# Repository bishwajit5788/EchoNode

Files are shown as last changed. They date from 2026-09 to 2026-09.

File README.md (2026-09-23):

# 🌙 EchoNode: Standalone Bedside Audio Player






**EchoNode** is an open-source, dedicated hardware bedside audio device engineered to solve a critical real-world problem: **preventing mobile phone dependency, eliminating cellular RF radiation, and silencing disruptive notifications right before and during sleep cycles.**

Built specifically for the **original Waveshare ESP32-S3-Touch-LCD-1.85 Development Board**, EchoNode delivers a zero-notification, dedicated bedside audio experience with strict memory lifecycle management, hardware safety policies, and a local web ingestion service.

---

## ⚡ Core Features

- 🎧 **Standalone SD Local Mode (Zero Radio):** Reads pure audio `.m4a` (AAC) or `.mp3` tracks directly from a FAT32 MicroSD card. Wi-Fi and Bluetooth baseband registers are powered off completely to maximize battery life and eliminate RF radiation.
- 🔊 **PCM5101 High-Fidelity Audio Core:** 3-wire I2S connection (`DIN=47`, `LRCK=38`, `BCK=48`) with internal PLL driving onboard miniature speakers.
- 💾 **TCA9554-Controlled MicroSD Storage:** Hardware Chip Select managed reliably through `EXIO3` on the onboard TCA9554 I2C IO expander (`0x20` on `SDA=11`, `SCL=10`).
- 🔄 **Real Finite State Machine & Memory Accounting:** Real FSM (`OFF`, `LOCAL_SD_STARTING`, `LOCAL_SD_ACTIVE`, `LOCAL_SD_STOPPING`, `BT_STARTING`, `BT_ACTIVE`, `BT_STOPPING`, `ERROR`) ensuring zero decoder leaks across repeated start/stop cycles.
- 📶 **Capability-Gated Bluetooth Architecture:** Deterministically reports `NOT_SUPPORTED` on ESP32-S3 due to absence of Classic Bluetooth (BR/EDR) hardware, maintaining architectural honesty while providing an extensible interface for future external Bluetooth coprocessors.
- 🛡️ **Built-in Safety Policies:**
  - `RULE_VOLUME_CEILING`: Digital volume hard-capped at $\le 65\%$ to prevent dynamic coil distortion and brownout voltage sags.
  - `RULE_I2S_MUTING`: Automatic hardware mute and DMA clearing on stop/pause to silence all ambient hiss and high-frequency EMI.
  - `RULE_THERMAL_SHUTDOWN`: 30-minute idle sleep timeout prevents heat entrapment near bedding and pillows.
  - 10-second automatic screen backlight dimming on `GPIO 5` for pitch-black sleep environments.
- 🌐 **Web Ingestion Hub:** FastAPI + `yt-dlp` local backend service that takes YouTube links, strictly strips video tracks, verifies **zero video streams** exist in the container, and formats them into clean `.m4a` files with FAT32-safe filenames for MicroSD transfer.
- 🎨 **Circular LVGL User Interface:** Custom UI tailored for the 360×360 ST77916 circular display (Screen Alpha: Clock/Battery/Mode, Screen Beta: 1Hz SD Player, Screen Gamma: Bluetooth Status).

---

<p align="center">
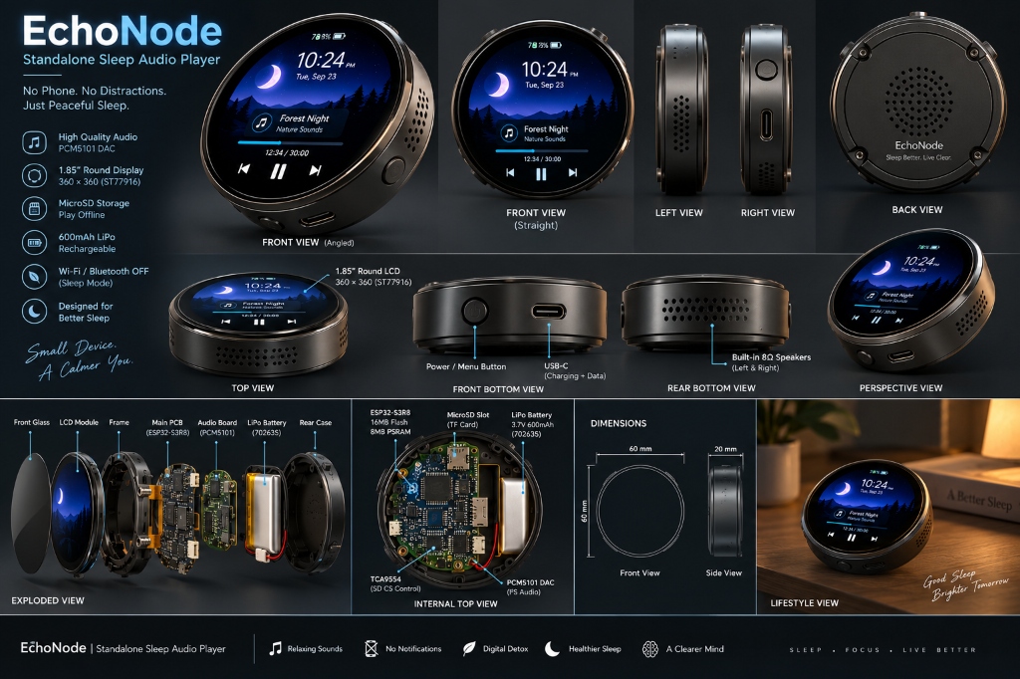
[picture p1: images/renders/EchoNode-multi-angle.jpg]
EchoNode Standalone Sleep Audio Player - Hardware Views & Dimensions
  
</p>

---

## 📁 Repository Structure

```
EchoNode/
├── images/                   # Visual documentation, 3D renders, components & assembly photos
│   ├── renders/              # Multi-angle product render, exploded view & dimensions
│   ├── components/           # Unboxing & bench photos of bare hardware modules
│   ├── assembly/             # Step-by-step physical assembly & wiring photos
│   └── prototype/            # Bench testing, diagnostic screen & power measurements
├── backend/                  # FastAPI web service, extraction worker & persistent storage
│   ├── app/                  # Application routes, models, config, and extractor service
│   │   └── services/         # Audio extractor, persistent SQLite JobStore, and StorageService
│   ├── worker.py             # Standalone persistent extraction worker microservice
│   ├── static/               # Modern dark-mode web dashboard UI
│   ├── tests/                # Unit tests, lifecycle audits, and audio-only validation
│   ├── downloads/            # Staged audio files ready for SD transfer
│   ├── requirements.txt      # Python dependencies
│   └── .env.example          # Environment variables template (WORKER_URL, S3, cookies)
├── firmware/                 # Production firmware for original Waveshare ESP32-S3 Round LCD
│   ├── include/              # Hardware pinouts, TCA9554 driver, FSM, and LVGL config
│   ├── src/                  # Audio manager, display manager, power manager, SD manager
│   ├── platformio.ini        # PlatformIO build configuration (16MB Flash, 8MB PSRAM OPI)
│   └── partitions_16MB.csv   # Audited flash partition table (4MB app0, 4MB app1, 2MB spiffs)
├── tools/                    # Verification & diagnostic utilities
│   ├── audit_pin_mappings.py # Validates GPIOs against authoritative Waveshare original board mapping
│   ├── check_partitions.py   # Validates partition boundaries and 4KB/64KB alignments
│   ├── generate_test_tones.py# Uncompressed 440Hz / stereo sweep hardware test tones
│   └── sd_card_verifier.py   # FAT32 and read/write throughput validator
├── enclosure/                # Parametric 3D printable bedside case (OpenSCAD)
├── docs/                     # Detailed wiring guides, assets and hardware interconnects
├── ARCHITECTURE.md           # System topology and state machine matrix
├── DESIGN.md                 # LVGL UI guidelines and screen coordinate maps
├── MEMORY.md                 # Flash partitioning and PSRAM/SRAM allocation rules
├── PDR.md                    # Product Design Requirements specification
├── RULES.md                  # Safety directives and firmware policies
└── TASK.md                   # Project engineering task roadmap
```

---

## 🚀 Quickstart Guide

### 1. Developer Commands (`make`)

The repository includes a comprehensive `Makefile` for developer workflows:

```bash
make help               # List all developer targets
make audit-pins         # Verify hardware pin definitions against authoritative Waveshare original spec
make check-partitions   # Verify 4KB/64KB flash partition alignments and boundaries
make test-backend       # Run backend unit tests and audio-only validation
make test-tones         # Generate uncompressed hardware test tones in backend/downloads/
make verify-sd          # Check and benchmark connected MicroSD card
make run-backend        # Start FastAPI YouTube extraction hub on http://localhost:8000
```

### 2. Flashing the ESP32-S3 Firmware

```bash
cd firmware

# Flash main bedside player firmware
pio run -e waveshare_esp32s3_round --target upload

# Or flash on-board hardware diagnostic self-test
pio run -e diagnostics --target upload

# Monitor serial output at 115200 baud
pio run --target monitor
```

---

## ⚠️ Hardware Safety Directives

* **`RULE_POLARITY_CHECK`:** Before connecting any battery to the board's MX1.25 connector, verify the positive and negative leads against the PCB silkscreen with a digital multimeter. Swapped polarity will destroy the onboard charging IC.
* **MicroSD Requirements:** Use cards $\le 32\text{GB}$ formatted as **FAT32**.
* **Charging Safety:** Never recharge the unit beneath pillows, blankets, or bedding.

---

## 📄 License
This project is open-source under the [MIT License](LICENSE).

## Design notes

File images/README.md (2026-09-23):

# 📸 EchoNode Image & Media Documentation

This directory houses all visual documentation, design renders, component photos, and assembly build logs for the **EchoNode Bedside Audio Player** project.

---

## 📁 Directory Structure

```
images/
├── README.md               # Visual asset guidelines and hardware photo staging
├── renders/                # High-resolution 3D CAD renders and infographics
│   └── EchoNode-multi-angle.jpg  # Multi-angle product render, exploded view & dimensions
├── components/             # Unboxing & bench photos of bare hardware modules
│   └── .gitkeep            # Staging for received components (Waveshare LCD, PCM5101, speakers, LiPo)
├── assembly/               # Step-by-step physical assembly & wiring photos
│   └── .gitkeep            # Staging for soldering, harness routing, and enclosure fitting
└── prototype/              # Bench testing, oscilloscope/multimeter verification, and live demos
    └── .gitkeep            # Staging for diagnostic screen, sleep test, and battery measurement
```

---

## 🖼️ Active Visual Assets

### 1. `renders/EchoNode-multi-angle.jpg`
* **Resolution:** 1024 × 682 (Standard 3:2 JFIF baseline JPEG)
* **SHA-256:** `88f4ac985d4829291b5230c04ee474b6b42d16b2e5aad39184ccdff016021594`
* **Contents:**
  - **Front View (Angled & Straight):** 360×360 ST77916 circular display running Screen Beta (album art, track time, volume ceiling indicator).
  - **Side Views (Left & Right):** Low-profile knurled control ring and CNC machined bevels.
  - **Back View:** Perforated acoustic speaker grille with 8Ω driver venting.
  - **Exploded View:** Front glass, circular LCD module, structural frame, main ESP32-S3R8 PCB, PCM5101 DAC board, 600mAh LiPo battery (702635), and rear case.
  - **Internal Top View:** Authoritative Waveshare board layout showing ESP32-S3R8 (16MB Flash, 8MB PSRAM), MicroSD slot, TCA9554 IO expander (EXIO3 CS), PCM5101 DAC I2S interface, and LiPo battery header.
  - **Dimensions:** 60 mm diameter × 20 mm thickness.
  - **Lifestyle Context:** Bedside table placement demonstrating zero phone distraction.

---

## 🛠️ Hardware Procurement & Photo Checklist

When physical components are received, add photos according to the following conventions:

### `components/` (Hardware Sourcing)
* `esp32s3_waveshare_front.jpg` — Original Waveshare ESP32-S3-Touch-LCD-1.85 front with circular LCD.
* `esp32s3_waveshare_back.jpg` — PCB backside showing silkscreen, TCA9554, and JST headers.
* `pcm5101_dac_board.jpg` — Audio DAC board showing 3-wire I2S pins (DIN=47, LRCK=38, BCK=48).
* `speakers_8ohm.jpg` — Dual 8Ω miniature acoustic drivers with JST-PH 2.0 connectors.
* `lipo_battery_polarity.jpg` — KP 702635 600mAh battery showing multimeter polarity check (`RULE_POLARITY_CHECK`).
* `enclosure_3d_print.jpg` — 3D printed bedside case parts (`echonode_bedside_case.scad`).

### `assembly/` (Build Progression)
* `01_polarity_verification.jpg` — Multimeter verifying battery connector polarity against silkscreen.
* `02_speaker_wiring.jpg` — Speaker wires terminated to JST-PH 2.0 headers.
* `03_board_stack_install.jpg` — Securing PCB and DAC inside lower enclosure shell.
* `04_battery_placement.jpg` — Battery seated in isolated tray away from heat-generating components.
* `05_final_closure.jpg` — Snapping enclosure lid and checking button/port clearances.

### `prototype/` (Bench Verification)
* `bench_diagnostics_screen.jpg` — Unit running `[env:diagnostics]` with hardware self-test pass.
* `bench_playback_screen.jpg` — Unit playing 440Hz sine test tone or local SD track.
* `current_draw_sleep.jpg` — Multimeter / Nordic Power Profiler showing deep sleep current consumption.

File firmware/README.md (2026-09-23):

# EchoNode Firmware - Waveshare ESP32-S3 1.85" Round Display

This directory contains the production firmware for the **EchoNode Bedside Audio Player**, engineered specifically for the **original Waveshare ESP32-S3-Touch-LCD-1.85 Development Board**.

---

## ⚠️ Mandatory Safety Verification Directives

Before connecting any battery or flashing, review and execute these directives:

### 1. `RULE_POLARITY_CHECK` (Hardware First Step)
* Inspect the **MX1.25** LiPo battery connector pins on your battery and the silkscreen markings (`+` / `-`) on the Waveshare PCB.
* **Test with a digital multimeter:** Ensure the positive lead matches `V_BAT` / `+` and negative lead matches `GND` / `-`.
* *Reversed polarity will instantly destroy the onboard lithium battery charging IC.*

### 2. `RULE_VOLUME_CEILING`
* Digital volume is locked in firmware to $\le 65\%$ (`HARD_MAX_VOLUME_LEVEL = 14 / 21`).
* This protects the 8Ω micro-speakers from excessive coil travel and prevents sudden current spikes that trigger battery voltage sags and brownout resets (`TG1WDT_SYS_RESET`).

### 3. `RULE_I2S_MUTING`
* When audio stops or pauses, the I2S bus is zeroed and clocks are muted, cutting off all residual high-frequency idle hiss and electromagnetic interference while you sleep.

### 4. `RULE_THERMAL_SHUTDOWN`
* If audio runs continuously for longer than 30 consecutive minutes without user interaction (`INACTIVITY_TIMEOUT_MS`), the unit triggers deep sleep, cutting off the display backlight on GPIO5 to prevent heat accumulation near bedding.

---

## 🖧 System Architecture & Hardware Truth

* **Target Board:** Original Waveshare ESP32-S3-Touch-LCD-1.85 (ESP32-S3R8, 16MB Flash, 8MB PSRAM OPI).
* **Audio Core:** PCM5101 3-Wire I2S DAC (DIN=47, LRCK=38, BCK=48) with internal PLL.
* **MicroSD Interface:** SPI bus (SCK=14, MISO=16, MOSI=17) with Chip Select routed through **TCA9554 EXIO3** (`0x20` on I2C SDA=11, SCL=10).
* **Display Interface:** 360x360 ST77916 QSPI LCD (DATA0=46, DATA1=45, DATA2=42, DATA3=41, SCK=40, CS=21, BL=5).
* **Flash Partitioning:** 16MB Quad-SPI flash configured with `partitions_16MB.csv` (4MB primary app, 4MB OTA rollout, 2MB LittleFS UI assets, verified via `tools/check_partitions.py`).
* **RAM / PSRAM Strategy:**
  * **Internal SRAM:** Dedicated to real-time I2S DMA ring buffers.
  * **8MB PSRAM (OPI):** Used for LVGL line buffers (`360x40`) and SD file chunk stream caching.
* **Bluetooth Classic Reality:**
  * The ESP32-S3 SoC physically lacks Classic Bluetooth (BR/EDR). Bluetooth A2DP Sink is not supported on bare ESP32-S3.
  * The firmware implements a capability-gated `IBluetoothAudio` interface that reports `NOT_SUPPORTED` on ESP32-S3, keeping wireless radios unpowered during local playback.

---

## 🛠️ Build & Flash Instructions

### Prerequisites
* [PlatformIO Core or VS Code Extension](https://platformio.org/) installed.

### Flashing via PlatformIO
```bash
# Navigate to firmware directory
cd firmware

# 1. Compile and flash main firmware
pio run -e waveshare_esp32s3_round --target upload

# 2. Or flash hardware bench diagnostic self-test
pio run -e diagnostics --target upload

# 3. Open serial monitor (115200 baud)
pio run --target monitor
```

---

## 🎵 Preparing the MicroSD Card

1. Use a MicroSD card $\le 32\text{GB}$.
2. Format the card as **FAT32** using standard allocation unit sizes.
3. Validate your card using `tools/sd_card_verifier.py`.
4. Use the EchoNode Web Scraper backend (`http://localhost:8000`) to extract pure audio-only `.m4a` files directly from YouTube and copy them to the card root directory.

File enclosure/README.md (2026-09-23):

# 🖨️ EchoNode Bedside 3D Printable Enclosure

This directory contains the parametric 3D CAD design for the **EchoNode Bedside Audio Player** enclosure, authored in [OpenSCAD](https://openscad.org/).

---

## 📐 Design Specifications

* **Form Factor:** Low-profile circular bedside puck ($\varnothing 82.0\text{ mm} \times 34.0\text{ mm}$ total height).
* **Display Aperture:** Recessed bezel lip sized for the Waveshare ESP32-S3 1.85-inch Circular Display ($360 \times 360$).
* **Internal Battery Vault:** Isolated compartment dedicated to the **KP Original 702635 600mAh LiPo** ($7.0\text{mm} \times 26.0\text{mm} \times 35.0\text{mm}$) with perimeter air gaps to prevent mechanical compression and heat accumulation near pillows.
* **Dual Acoustic Chambers:** Symmetrical side sound chambers with resonance slits for dual 8Ω micro-speakers connected via JST-PH 2.0 headers.
* **I/O Service Ports:** Recessed cutouts for USB-C (charging & serial) and the MicroSD card push-pull slot.

---

## ⚙️ Recommended Slicer Settings

| Parameter | Recommended Value | Notes |
| :--- | :--- | :--- |
| **Material** | **PETG** (Recommended) or PLA+ | PETG offers superior heat and creep resistance near bedding. |
| **Layer Height** | `0.16 mm` or `0.20 mm` | `0.16 mm` gives smoother circular rim slopes. |
| **Perimeters / Walls** | `3 to 4 walls` | Adds rigidity to protect internal LiPo cell from external weight. |
| **Infill Density** | `25% - 30%` | Gyroid or Honeycomb for balanced acoustic dampening. |
| **Supports** | Minimal / None | Top and bottom shells are oriented flat on the build plate. |

---

## 🛠️ Assembly Instructions

1. **Battery Insertion & Polarity Verification:**
   * Place the KP 702635 battery into the central isolation tray in the bottom shell.
   * **`RULE_POLARITY_CHECK`:** Double-check red (`+`) and black (`-`) wires against the Waveshare PCB silkscreen with a multimeter before connecting the MX1.25 plug.
2. **Speakers:**
   * Slide the two 8Ω micro-speakers into their dedicated left and right acoustic cavities in the bottom shell. Connect to the JST-PH 2.0 headers.
3. **Display & PCB:**
   * Seat the Waveshare 1.85" round display board into the top shell's recessed mounting shelf.
4. **Enclosure Closure:**
   * Align top and bottom shells and fasten using 4x `M2` or `M2.5` $\times 12\text{mm}$ screws through the counter-bored holes on the bottom shell.

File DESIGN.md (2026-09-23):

# Graphical Interface Design & Display Architecture

## 1. Frame Buffer Coordinates & Visual Form Factors
*   **Display Geometry:** Perfect 1:1 circular screen layout.
*   **Pixel Matrix:** 360x360 resolution frame limits on ST77916 QSPI display.
*   **Backlight Control:** PWM controlled via `GPIO 5`.
*   **Graphics Engine:** UI construction utilizing the LVGL 8.3 framework with PSRAM framebuffers to protect internal SRAM for audio DMA.

## 2. Interactive Page Layouts

### Screen Alpha: Boot / Standby Dashboard
*   **Central Asset:** Large digital time readout refreshed cleanly from the internal Real-Time Clock (RTC).
*   **Status Bars:** A battery fuel gauge tracking voltage changes via ADC (GPIO1) and displaying a low power visual warning when cells descend to 3.5V.
*   **Control Mechanisms:** Two distinct profile selector buttons:
    *   Button Left: [Standalone SD Local Profile] - Enters local SD playback.
    *   Button Right: [Bluetooth Audio (Gated)] - Leads to Screen Gamma status display.

### Screen Beta: Standalone Local Playback Interface
*   **Static Rendering:** Audio metadata tracking lines and layout frames remain strictly static to reduce SPI bus congestion.
*   **Dynamic Truncation:** Playback time status text digits update exactly once per second (1Hz), minimizing display refreshes to avoid introducing line audio crackle.
*   **Volume Ceiling Indicator:** Explicitly displays current volume and indicates the hard safety cap of 65%.
*   **Control Matrix:** Minimalist navigation buttons (Play/Pause/Next/Prev/Return-To-Menu). The panel backlight shuts off completely after 10 seconds of user interaction idle timeouts (`DISPLAY_IDLE_TIMEOUT_MS`).

### Screen Gamma: Bluetooth Hardware Capability Status
*   **Truthful Hardware Status:** Does NOT fake an active A2DP discovery sequence.
*   **Notice Field:** Displays "Bluetooth Audio Unavailable" informing the user that the ESP32-S3 SoC physically lacks Classic Bluetooth (BR/EDR) hardware.
*   **Return Interface:** A high-visibility tactile boundary escape button to jump safely back to Standby.

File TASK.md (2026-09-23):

# Project Engineering Task Tracking & Execution Plan

### PHASE 1: Web Scraper Backend Architecture Setup
- [x] Initialize standard Python workspace structure utilizing FastAPI framework rules. *(Verified via automated test suite)*
- [x] Deploy yt-dlp dependencies and configuration scripts. *(Verified via automated test suite)*
- [x] Enforce output filter rules to strip out raw video tracks, saving files purely into audio-only M4A containers. *(Verified via test_audio_only.py)*
- [x] Test the pipeline on local machines using sample YouTube links to verify pure audio output functionality. *(Verified via test_extraction_live.py)*

### PHASE 2: Core Hardware Diagnostics & Bench Tooling
- [x] Implement on-board hardware diagnostic self-test suite (`hardware_diagnostics.cpp` & `[env:diagnostics]`). *(Verified in firmware source tree)*
- [x] Implement uncompressed hardware test tone generators for bench frequency sweeps (`tools/generate_test_tones.py`). *(Verified via automated script)*
- [x] Implement MicroSD card FAT32 validator & throughput benchmark tool (`tools/sd_card_verifier.py`). *(Verified via CLI test)*
- [ ] **Physical bench verification:** Perform multimeter tests on battery connector pins against PCB silkscreen (`RULE_POLARITY_CHECK`). *[Physical Bench Pending]*
- [ ] **Physical bench verification:** Wire dual 8Ω micro-speakers via JST-PH 2.0 headers and run on-board tone check sweep. *[Physical Bench Pending]*
- [ ] **Physical bench verification:** Insert physical <=32GB FAT32 MicroSD card and verify on-board mount via TCA9554 EXIO3 CS. *[Physical Bench Pending]*

### PHASE 3: Memory-Safe Firmware Synthesis
- [x] Reconcile authoritative Waveshare ESP32-S3-Touch-LCD-1.85 original pin mapping (LCD, SD, PCM5101, I2C). *(Verified via tools/audit_pin_mappings.py)*
- [x] Eliminate prohibited ESP32-A2DP dependency; implement capability-gated `IBluetoothAudio` interface reporting `NOT_SUPPORTED` on ESP32-S3. *(Verified via CI & audit)*
- [x] Implement real finite state machine (`state_machine.h`) enforcing transition lifecycle: `ACTIVE_A -> mute -> stop -> destroy -> free -> clear pointers -> verify resources -> ACTIVE_B`. *(Verified in audio_manager.cpp)*
- [x] Build TCA9554 IO expander driver controlling MicroSD CS on EXIO3 (`tca9554.cpp` & `sd_manager.cpp`). *(Verified in firmware codebase)*
- [x] Implement deterministic hardware PCM/I2S test path and <=65% volume ceiling enforcement (`RULE_VOLUME_CEILING`). *(Verified in audio_manager.cpp)*
- [ ] **Physical bench verification:** Run continuous start/stop playback cycles on physical ESP32-S3 hardware to record internal heap and PSRAM stability. *[Physical Bench Pending]*

### PHASE 4: Visual Interface & Enclosure Design
- [x] Integrate LVGL 8.3 geometry loops for 360x360 ST77916 circular LCD with PSRAM framebuffers. *(Verified in display_manager.cpp)*
- [x] Implement Screen Alpha (clock, battery, local SD mode, capability-gated BT mode). *(Verified in display_manager.cpp)*
- [x] Implement Screen Beta with strictly 1Hz dynamic updates and volume ceiling indicator. *(Verified in display_manager.cpp)*
- [x] Implement Screen Gamma truthfully explaining Bluetooth Audio is unavailable on ESP32-S3 (no fake A2DP discovery). *(Verified in display_manager.cpp)*
- [x] Implement configurable 30-min idle sleep (`RULE_THERMAL_SHUTDOWN`) and 10s display dimming on GPIO5. *(Verified in power_manager.cpp)*
- [x] Create parametric 3D printable bedside enclosure in OpenSCAD with isolated battery tray and acoustic chambers (`enclosure/echonode_bedside_case.scad`). *(Verified in CAD model)*
- [x] Add high-resolution multi-angle product render, exploded view and visual media structure (`images/README.md`, `images/renders/`, `images/components/`, `images/assembly/`, `images/prototype/`). *(Verified)*

### PHASE 5: Deployment, CI/CD & Open-Source Release
- [x] Create `check_partitions.py` tool verifying 4KB sector alignment, 64KB MMU OTA alignment, and no overlaps. *(Verified against partitions_16MB.csv)*
- [x] Create `audit_pin_mappings.py` verifying exact GPIOs against authoritative Waveshare original board mapping. *(Verified)*
- [x] Update GitHub Actions CI workflow (`.github/workflows/ci.yml`) to run pin audits, partition checks, backend tests, and firmware builds. *(Verified)*
- [x] Synchronize all master documentation files (`PDR.md`, `ARCHITECTURE.md`, `RULES.md`, `DESIGN.md`, `MEMORY.md`, `README.md`, `docs/wiring_guide.md`). *(Verified)*

### PHASE 6: Cloud Deployment & Serverless Runtime Hardening
- [x] Harden backend for serverless deployment on Vercel (`downloads_dir` fallback to writable `/tmp/downloads`). *(Verified on live Vercel)*
- [x] Mitigate serverless container freeze by awaiting extraction within request lifecycle on `VERCEL=1`. *(Verified on live Vercel)*
- [x] Add player client fallbacks (`android`, `ios`, `mweb`, `web`) and `YTDLP_COOKIES` environment variable support to bypass datacenter IP bot detection. *(Verified in extractor.py)*
- [x] Surface real-time backend errors (`job.error`) directly inside web dashboard UI. *(Verified in index.html)*
- [x] Document local vs cloud deployment architectures in `backend/README.md`. *(Verified)*

### PHASE 7: Decoupled Extraction Architecture & Production YouTube Audio Engine
- [x] Root-cause diagnosis of YouTube BotGuard datacenter IP challenges and Vercel serverless execution limits. *(Documented in implementation_plan.md)*
- [x] Implement persistent SQLite-backed `JobStore` surviving serverless cold starts and worker restarts. *(Verified via test_job_store.py)*
- [x] Implement pluggable `StorageService` supporting local staging and S3/R2/MinIO cloud object storage. *(Verified via test_storage.py)*
- [x] Implement error message sanitization preventing credentials, session tokens, or private paths from leaking to logs or API responses. *(Verified via test_job_store.py)*
- [x] Implement standalone worker service entrypoint (`backend/worker.py`) with FFmpeg transcoding, pure audio validation, and secure temporary cookie handling. *(Verified via worker.py)*
- [x] Implement Vercel proxy coordinator mode (`WORKER_URL`) maintaining identical API routes (`/api/extract`, `/api/jobs`, `/api/files`, `/api/download/{filename}`). *(Verified via test_backend.py)*
- [x] Enforce pure audio stream validation (0 video tracks), $\le 60$ MB size limits, and FAT32 filename sanitization. *(Verified via test_audio_only.py)*
- [x] Create comprehensive Phase 7 verification test suite (`backend/tests/test_phase7_verification.py`). *(Verified via 11 automated test cases)*
- [x] Update GitHub Actions CI workflow to run all backend test suites and compile production firmware (`pio run -e waveshare_esp32s3_round`). *(Verified in .github/workflows/ci.yml)*

### PHASE 8: Production Ingestion Pipeline Hardening & 22-Requirement Suite
- [x] Eliminate silent serverless fallback in Vercel: return predictable HTTP 503 (`{"error": "Extraction worker is not configured"}`) when `WORKER_URL` is unset. *(Verified on live Vercel)*
- [x] Standardize `/api/system-info` and `/health` with non-secret operational diagnostics. *(Verified live on Vercel)*
- [x] Deploy Proof-of-Origin (POT) provider support (`bgutil-ytdlp-pot-provider`) and `ejs:github` JavaScript challenge solving. *(Verified in extractor.py)*
- [x] Enforce pure audio format selector (`140/bestaudio[ext=m4a]/bestaudio`) preventing video fallback. *(Verified via test_all_22_requirements.py)*
- [x] Implement comprehensive 22-requirement test suite (`backend/tests/test_all_22_requirements.py`). *(22/22 passed)*
- [x] Provide production Dockerfile and `docker-compose.yml` for persistent extraction worker with BgUtils POT daemon and Node.js challenge solver. *(Verified)*
- [x] Update frontend dashboard (`index.html`) with dynamic worker connection status badges. *(Verified live on Vercel)*
- [x] Update GitHub Actions CI with `workflow_dispatch` opt-in live YouTube extraction test. *(Verified in .github/workflows/ci.yml)*

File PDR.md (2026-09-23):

# Product Design Requirements (PDR) - Bedside Audio Device

## 1. Vision & Core Objective
A small, dedicated, hardware-based standalone bedside music player engineered to solve a critical real-world problem: preventing mobile device dependency, cellular thermal radiation, and distracting notification interruptions right before or during sleep.

## 2. Targeted Hardware Environment
*   **Core Controller:** Waveshare ESP32-S3-Touch-LCD-1.85 Development Board (Original Revision).
    *   **Processor:** 32-bit LX7 dual-core running up to 240MHz (ESP32-S3R8).
    *   **Memory Footprint:** 16MB Quad Flash, 8MB Octal PSRAM.
    *   **Display Spec:** 360x360 circular LCD panel (ST77916 QSPI: DATA0=46, DATA1=45, DATA2=42, DATA3=41, SCK=40, CS=21, BL=5).
    *   **Audio Core:** Onboard PCM5101 3-wire I2S DAC (DIN=47, LRCK=38, BCK=48) coupled with onboard speaker amplifier and JST-PH 2.0 miniature speaker pinouts.
*   **Acoustics:** Dual 8Ω micro-speakers connected directly via JST-PH 2.0 cables.
*   **Power System:** KP Original 702635 600mAh 3.7V single-cell rechargeable Lithium-Polymer (LiPo) battery.
*   **Storage Expansion:** MicroSD Card slot (FAT32, restricted to <= 32GB; SPI interface: MISO=16, MOSI=17, SCK=14, CS=TCA9554 EXIO3).
*   **IO Expander & Peripherals:** TCA9554 at I2C `0x20` (SDA=11, SCL=10), CST816S touch controller at `0x15`, PCF8563 RTC at `0x51`.

## 3. Web Service Specifications
*   **Functionality:** A minimalist web service interface capable of taking a user-submitted YouTube URL link.
*   **Extraction Engine:** Automated extraction of video containers down to video-free audio-only streams wrapped inside `.m4a` or `.mp3` files.
*   **Container Validation:** Strict rejection of any container holding a video stream track.
*   **Fulfillment Pipeline:** Transfer mechanism targeting storage expansion via physical SD Card swapping, USB-C Mass Storage drive emulation, or local home Wi-Fi network POST synchronization loops.

## 4. Operational Boundaries & Constraints
*   **Zero Notification Environment:** The system must enforce absolute isolation from cellular push payloads during sleep cycles.
*   **Bluetooth Classic Reality:** The ESP32-S3 SoC physically lacks Classic Bluetooth (BR/EDR). Bluetooth A2DP Sink is not supported on bare ESP32-S3; radios remain powered off during local playback.
*   **Thermal Safety:** Strict limits preventing operational heat entrapment when the device sits near bedding arrays or pillows. A 30-minute idle sleep timeout cuts off backlights. Recharging beneath pillows or bedding is strictly prohibited.
*   **Battery Power Sag:** Safe management of current demands enforcing a hard volume ceiling <= 65% to prevent internal system rails from sagging and tripping brownout loops.

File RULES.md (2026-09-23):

# Operational Safety, Firmware Policies & Constraints

## 1. Electrical & Thermal Safety Directives
*   **RULE_POLARITY_CHECK:** Before initial battery contact, the polarization vectors of the MX1.25 connector must be verified with a digital multimeter against the physical silkscreen marking on the Waveshare PCB. Swapped positive/negative leads will destroy the onboard charging integrated circuit.
*   **RULE_THERMAL_SHUTDOWN:** If internal audio loops run continuously for longer than 30 consecutive minutes without user input (`INACTIVITY_TIMEOUT_MS`), the system must invoke an automatic sleep timeout, cutting off display backlights on GPIO5 to eliminate risk of heat entrapment near bedding.
*   **RULE_CHARGING_SAFETY:** Never initiate cell recharging while the physical unit is positioned directly beneath or against pillows, blankets, or bedding. 

## 2. Firmware Compilation & Resource Policies
*   **RULE_MUTUAL_EXCLUSION:** Memory spaces dedicated to the SD audio track decoder and any wireless audio software stack must never coexist in RAM active allocations simultaneously. Transitioning between profiles requires explicit teardown, decoder destruction, buffer freeing, pointer clearing, and memory verification before establishing a new profile.
*   **RULE_VOLUME_CEILING:** Digital volume mapping configurations must be hard-capped at an upper boundary of <= 65% (`HARD_MAX_VOLUME_LEVEL = 14 / 21`). This prevents dynamic speaker coil distortion and guards against sudden voltage sags that trip brownout loop crashes.
*   **RULE_I2S_MUTING:** When playback is paused or the queue is fully cleared, the software must trigger code-level mute sequences on the I2S bus, clear DMA buffers, and disable active clocking to eliminate electromagnetic interference and residual high-frequency idle hiss.
*   **RULE_STORAGE_BOUNDARY:** MicroSD storage cards must strictly comply with FAT32 formatting and a capacity ceiling of <= 32GB to avoid unhandled exFAT cluster structures on the SPI bus.

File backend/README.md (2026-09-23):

# 🌐 EchoNode Ingestion Hub & Extraction Engine

The **EchoNode Ingestion Hub** converts YouTube URLs into pure, video-free `.m4a` (AAC-LC) audio streams tailored specifically for hardware decoding on the **EchoNode Bedside Audio Player** (Waveshare ESP32-S3-Touch-LCD-1.85 with PCM5101 I2S DAC).

---

## 🏛️ Production 3-Tier Architecture

To overcome cloud datacenter bot challenges and serverless compute/filesystem constraints, EchoNode uses a decoupled 3-tier production architecture:

```
Vercel Edge / Serverless
  ├── Web UI (Ambient Glassmorphism Dashboard)
  ├── Lightweight API Proxy / Coordinator
  └── Immediate Job Submission & Status Polling

Persistent Extraction Worker (Docker / VPS / Local Server)
  ├── yt-dlp Ingestion Engine
  ├── FFmpeg Transcoding Pipeline (~128 kbps AAC-LC)
  ├── Secure YouTube Access (YTDLP_COOKIES & PO-Token Support)
  └── Pure-Python ISO BMFF Container Verification (0 video tracks)

Persistent Storage Layer
  ├── SQLite Durable JobStore (echonode_jobs.db surviving reboots)
  └── Pluggable Storage (Local filesystem or S3 / Cloudflare R2 / MinIO)
```

---

## ⚡ Key Capabilities

* 🎵 **Pure Audio Containerization:** Strips all video tracks (`vide`), containerizing strictly to pure audio `.m4a` (AAC-LC) or `.mp3`.
* 🛡️ **Container Stream Auditing:** Pure-Python ISO BMFF atom parser inspects `moov/trak/mdia/hdlr` atoms to guarantee 0 video streams exist before staging.
* 💾 **FAT32 Filename Sanitization:** Enforces FAT32 character bounds (eliminates `/\:*?"<>|`) and limits title length to $\le 60$ characters.
* 🔒 **Zero-Secret Leakage Guarantee:** Credentials, cookie contents, session IDs, and tokens are scrubbed automatically from all error strings, API payloads, and log outputs.
* 📦 **Persistent Job State:** SQLite ACID storage preserves job history, states (`queued`, `processing`, `completed`, `failed`), and progress across process and container recycles.
* 🎛️ **Dual-Mode Operation:** Works out-of-the-box as a standalone local server or as a cloud proxy pointing to a persistent worker.

---

## 🚀 Running Locally (Standalone Mode)

Local execution uses your residential or office ISP connection, which is not flagged by YouTube datacenter IP reputation filters:

```bash
# Start standalone local ingestion server (UI + API + Worker on http://localhost:8000)
make run-backend
```

Open your browser to:
👉 **`http://localhost:8000`**

Extracted files are staged automatically in `backend/downloads/` ready for direct MicroSD card synchronization.

---

## ⚙️ Running the Dedicated Worker

For persistent cloud deployments (Vercel frontend + dedicated worker):

```bash
# Set environment secrets (optional for datacenter IPs)
export YTDLP_COOKIES="<contents of exported cookies.txt>"
export PORT=8001

# Start worker service
make run-worker
# Or: python backend/worker.py
```

### Configuring Vercel to use the Persistent Worker

In the Vercel Project Dashboard -> **Settings** -> **Environment Variables**:
* **`WORKER_URL`**: `https://your-worker-domain.com` (e.g. deployed on Fly.io, Railway, VPS, or tunnel)

When `WORKER_URL` is set, Vercel acts as a lightweight proxy, instantly forwarding extraction requests and status queries to your worker.

---

## 🔒 Secure YouTube Authentication Configuration

YouTube's BotGuard restricts unauthenticated access from major cloud datacenter IP ranges (AWS, GCP, Azure, Oracle).

### Supported Secure Authentication Methods

1. **`YTDLP_COOKIES` (Environment Variable)**:
   Export your YouTube cookies in Netscape format (using browser extensions such as *Get cookies.txt locally* in an incognito window).
   Set the content as a server-side secret environment variable:
   ```bash
   YTDLP_COOKIES="# Netscape HTTP Cookie File\n# ..."
   ```
   *Security Note: The worker writes cookies to a temporary file with strict `0600` permissions and automatically shreds/deletes it upon job completion.*

2. **`YTDLP_COOKIES_PATH` (File Path)**:
   Point to a secure, gitignored file on the server filesystem:
   ```bash
   YTDLP_COOKIES_PATH=/etc/echonode/cookies.txt
   ```

3. **Cookie Rotation Guidelines**:
   - YouTube session cookies typically remain valid for several weeks to months.
   - When a session expires, export fresh cookies from your browser and update the environment secret.
   - **NEVER** commit cookie files to version control (`.gitignore` enforces this).
   - **NEVER** expose cookies to frontend JavaScript.

---

## 📡 API Reference

Interactive Swagger documentation is available at `/docs`, with OpenAPI JSON at `/openapi.json`.

| Endpoint | Method | Description |
|---|---|---|
| `/` | `GET` | Ambient dark-mode web dashboard UI |
| `/health` | `GET` | Health check returning status, app name, and version |
| `/api/system-info` | `GET` | Storage stats, worker mode, downloads directory, and FFmpeg detection |
| `/api/extract` | `POST` | Submits a YouTube link for pure audio extraction |
| `/api/jobs` | `GET` | Lists all active and completed extraction jobs |
| `/api/jobs/{job_id}` | `GET` | Status (`queued`, `processing`, `completed`, `failed`), progress %, and sanitized error diagnosis |
| `/api/files` | `GET` | Lists all staged audio tracks ready for MicroSD card transfer |
| `/api/download/{filename}` | `GET` | Streams or downloads a specific staged audio track |
| `/api/files/{filename}` | `DELETE` | Deletes a staged audio track from disk/storage |
| `/api/sync-sd` | `POST` | Copies all staged audio files to a mounted MicroSD card path |

---

## 🧪 Testing & Verification

```bash
# Run all backend unit and architecture tests:
make test-backend

# Individual test suites:
python backend/tests/test_job_store.py              # SQLite persistence & error sanitization
python backend/tests/test_storage.py                # Local & S3 storage adapters
python backend/tests/test_backend.py                # Route validation & error handling
python backend/tests/test_audio_only.py             # ISO BMFF pure audio stream validation
python backend/tests/test_phase7_verification.py   # Comprehensive Phase 7 pipeline validation
```

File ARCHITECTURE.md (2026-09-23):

# System Architecture & Technical Topology

## 1. Dual Operational Profile Matrix & Hardware Capability Gating

```
┌────────────────────────────────────────────────────────┐
│               ESP32-S3 Firmware System                 │
└───────────────────────────┬────────────────────────────┘
                            │
┌───────────────────────────┴───────────────────────────┐
▼                                                       ▼
┌───────────────────────────────┐       ┌───────────────────────────────┐
│     Standalone SD Mode        │       │     Bluetooth Audio Mode      │
├───────────────────────────────┤       ├───────────────────────────────┤
│ • Wi-Fi / Bluetooth: OFF      │       │ • Capability-Gated Interface  │
│ • Reads M4A/MP3 from SD card  │       │ • ESP32-S3 lacks Classic BT   │
│ • Zero phone notifications    │       │ • Reports NOT_SUPPORTED       │
│ • Maximum battery savings     │       │ • Extensible for external copr│
│ • PCM5101 I2S Output          │       │ • Radios remain unpowered     │
└───────────────────────────────┘       └───────────────────────────────┘
```

## 2. Memory Mutual Exclusion Finite State Machine (FSM)

The firmware enforces strict resource mutual exclusion through a deterministic state machine:

```
               ┌───────────┐
               │    OFF    │◄────────────────────────┐
               └─────┬─────┘                         │
                     │                               │
        ┌────────────┴────────────┐                  │
        ▼                         ▼                  │
┌──────────────────┐     ┌──────────────────┐        │
│LOCAL_SD_STARTING │     │   BT_STARTING    │        │
└───────┬──────────┘     └────────┬─────────┘        │
        │                         │ (Unsupported on  │
        ▼                         │  ESP32-S3 SoC)   │
┌──────────────────┐              ▼                  │
│ LOCAL_SD_ACTIVE  │     ┌──────────────────┐        │
└───────┬──────────┘     │    BT_STOPPING   │────────┘
        │                └──────────────────┘
        ▼
┌──────────────────┐
│LOCAL_SD_STOPPING │─────────────────────────────────┘
└──────────────────┘
```

### Transition Guarantee:
`ACTIVE_A -> mute audio -> stop stream -> destroy decoder -> free heap/PSRAM -> clear pointers -> verify resources -> ACTIVE_B`

* No global `Audio` object.
* No static instances of decoders.
* Explicit heap and PSRAM accounting before allocation and after destruction to prevent memory fragmentation and leaks.

## 3. Subsystem Breakdowns

### A. Web Server Backend Data Path
1. **Link Capture:** Web UI dashboard receives an online URL string via standard JSON POST request payloads.
2. **URL Validation:** Strict regex and hostname verification restricting to YouTube domains, rejecting shell injection characters.
3. **Stream Stripping:** `yt-dlp` captures the online target isolating raw audio stream channels (`140/bestaudio[ext=m4a]`) while ignoring data-heavy visual tracks.
4. **Media Container Audit:** Inspects media container atoms (`moov/trak/hdlr`) to verify **zero video streams** exist. Rejects and purges any file with video tracks.
5. **Sanitization:** Sanitizes output filenames against FAT32 illegal characters (`/ \ : * ? " < > |`) to prevent MicroSD read errors.

### B. Embedded Playback Pipeline
*   **Storage Access:** SPI communication interface (SCK=14, MISO=16, MOSI=17) with Chip Select driven via `EXIO3` on the onboard `TCA9554` I2C IO expander (`0x20`).
*   **Audio Engine:** Stream blocks pass into dynamically allocated `ESP32-audioI2S` instances.
*   **Signal Output:** Digital audio blocks map onto physical 3-wire I2S lines (`DIN=47`, `LRCK=38`, `BCK=48`), passing into the onboard `PCM5101` DAC with internal PLL to power connected 8Ω micro-speakers.

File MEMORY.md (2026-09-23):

# Memory Allocation & Hardware Partition Layout

## 1. Storage Flash Layout Structure (16MB Onboard Flash)

Validated via `tools/check_partitions.py` against `firmware/partitions_16MB.csv`:

```
0x000000 ┌──────────────────────────────────────────────┐
         │ Bootloader (32 KB) + Partition Table (4 KB)  │
0x009000 ├──────────────────────────────────────────────┤
         │ NVS (20 KB)                                  │
0x00E000 ├──────────────────────────────────────────────┤
         │ OTA Data (8 KB)                              │
0x010000 ├──────────────────────────────────────────────┤
         │ app0 (ota_0) - Primary Firmware (4.00 MB)    │
0x410000 ├──────────────────────────────────────────────┤
         │ app1 (ota_1) - Secondary Rollout (4.00 MB)   │
0x810000 ├──────────────────────────────────────────────┤
         │ SPIFFS / LittleFS - UI Assets (2.00 MB)      │
0xA10000 ├──────────────────────────────────────────────┤
         │ Unallocated Headroom / Expansion (5.94 MB)   │
0x1000000└──────────────────────────────────────────────┘
```

* **4KB Alignment:** All partition offsets and sizes are strictly aligned to 4096-byte boundaries.
* **64KB MMU Alignment:** Both `app0` (`0x10000`) and `app1` (`0x410000`) adhere to ESP32-S3 64KB MMU flash page boundaries.

---

## 2. Internal RAM & PSRAM Management Rules

### A. Local Storage File Playback Profile
*   **DMA Audio Channel Buffers:** Allocates real-time I2S transmit ring buffers inside fast internal SRAM to feed PCM5101 I2S clocks (`DIN=47`, `LRCK=38`, `BCK=48`) seamlessly without underruns.
*   **Audio File Stream Buffers:** Allocates incoming stream chunks and metadata structures into external 8MB PSRAM regions to conserve internal SRAM.
*   **LVGL Frame Buffers:** Allocates 360x40 line draw buffers in external PSRAM (`ps_malloc`) to avoid starving internal heap.
*   **Radio Transceiver Overhead:** Wireless transceivers are forced completely offline (`WiFi.mode(WIFI_OFF)`). Wi-Fi and Bluetooth baseband registers are unpowered.
*   **Leak Accounting:** Pre- and post-allocation memory snapshots are recorded upon every state transition to ensure zero memory leaks during repeated start/stop cycles.

### B. Mutual Exclusion & Lifecycle Protection
*   The decoder instance is created dynamically only when transitioning to `LOCAL_SD_ACTIVE`.
*   Upon stopping or entering standby, the decoder instance is explicitly stopped, deleted, its pointers set to `nullptr`, and SD storage unmounted.

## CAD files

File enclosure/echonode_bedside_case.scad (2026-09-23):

// ==============================================================================
// EchoNode - Bedside Audio Device 3D Printable Enclosure
// Target Board: Waveshare ESP32-S3 1.85-inch Round Display (360x360)
// Battery: KP Original 702635 600mAh LiPo (7mm x 26mm x 35mm)
// Acoustics: Dual 8-ohm micro-speakers with dedicated acoustic resonance chambers
// ==============================================================================

$fn = 90; // High resolution curves

// Part to render: "both", "top", "bottom", "exploded"
part = "both"; 

// --- Primary Dimensions (in mm) ---
case_od            = 82.0;  // Outer diameter of the bedside puck
case_height_top    = 16.0;  // Top shell height
case_height_bottom = 18.0;  // Bottom shell height
wall_thickness     = 2.4;   // Rigid outer shell thickness

// Display Aperture (Waveshare 1.85" round screen)
lcd_glass_dia      = 54.0;  // Active display + bezel diameter
lcd_view_dia       = 48.0;  // Viewable circular window
lcd_recess_depth   = 2.0;   // Seating step depth

// Battery Bay (KP Original 702635 600mAh LiPo: 7.0 x 26.0 x 35.0 mm)
batt_x             = 28.0;  // Margin + clearance
batt_y             = 37.0;
batt_z             = 8.0;

// Dual Speaker Chambers (15mm x 24mm micro-speakers)
spk_width          = 16.0;
spk_length         = 25.0;
spk_depth          = 6.5;

// Cutouts & Fasteners
usbc_w             = 10.0;
usbc_h             = 4.5;
sd_w               = 13.0;
sd_h               = 2.5;
screw_post_dia     = 6.0;
screw_hole_dia     = 2.2;   // For M2 self-tapping or heat-set insert

// ==============================================================================
// TOP SHELL MODULE
// ==============================================================================
module top_shell() {
    difference() {
        // Outer Body with smooth chamfered lip
        union() {
            cylinder(h = case_height_top - 2, d = case_od);
            translate([0, 0, case_height_top - 2])
                cylinder(h = 2, d1 = case_od, d2 = case_od - 4);
        }

        // Inner Cavity
        translate([0, 0, -1])
            cylinder(h = case_height_top - wall_thickness + 1, d = case_od - (wall_thickness * 2));

        // Circular Display Window (Aperture through the top)
        translate([0, 0, -1])
            cylinder(h = case_height_top + 3, d = lcd_view_dia);

        // Circular Display Recessed Rim (Seats the round glass/bezel flush)
        translate([0, 0, case_height_top - lcd_recess_depth])
            cylinder(h = lcd_recess_depth + 1, d = lcd_glass_dia);

        // Acoustic Grille Ports (Left & Right micro-speaker sound slits)
        for (side = [-1, 1]) {
            translate([side * (case_od / 2 - wall_thickness - 1), 0, case_height_top / 2]) {
                for (slot = [-10:4:10]) {
                    translate([0, slot, 0])
                        rotate([0, 90, 0])
                            cylinder(h = wall_thickness * 2 + 2, d = 1.6, center = true);
                }
            }
        }
    }

    // Screw Mounting Bosses (4x symmetrical alignment pillars)
    for (a = [45, 135, 225, 315]) {
        rotate([0, 0, a]) {
            translate([(case_od / 2) - wall_thickness - 4, 0, 0]) {
                difference() {
                    cylinder(h = case_height_top - wall_thickness, d = screw_post_dia);
                    cylinder(h = case_height_top, d = screw_hole_dia);
                }
            }
        }
    }

    // PCB Support Ledge for Waveshare Round Board
    difference() {
        translate([0, 0, case_height_top - lcd_recess_depth - 3.5])
            cylinder(h = 2.0, d = lcd_glass_dia + 4);
        translate([0, 0, case_height_top - lcd_recess_depth - 4])
            cylinder(h = 4.0, d = lcd_glass_dia - 1.5);
    }
}

// ==============================================================================
// BOTTOM SHELL MODULE
// ==============================================================================
module bottom_shell() {
    difference() {
        // Base Cylinder
        cylinder(h = case_height_bottom, d = case_od);

        // Internal Cavity
        translate([0, 0, wall_thickness])
            cylinder(h = case_height_bottom + 1, d = case_od - (wall_thickness * 2));

        // USB-C Charging & Programming Port Cutout
        translate([0, -(case_od / 2 + 1), wall_thickness + 3])
            cube([usbc_w, wall_thickness * 2 + 2, usbc_h], center = true);

        // MicroSD Access Slot (Opposite side)
        translate([0, (case_od / 2 + 1), wall_thickness + 3])
            cube([sd_w, wall_thickness * 2 + 2, sd_h], center = true);

        // Fastener Counter-Bores on the bottom exterior
        for (a = [45, 135, 225, 315]) {
            rotate([0, 0, a]) {
                translate([(case_od / 2) - wall_thickness - 4, 0, -1]) {
                    cylinder(h = wall_thickness + 2, d = screw_hole_dia + 0.4);
                    cylinder(h = 2.0, d = 4.5); // Screw head recess
                }
            }
        }
    }

    // Battery Isolation Tray (Prevents LiPo pressure against PCB & bedding)
    translate([0, 0, wall_thickness]) {
        difference() {
            translate([-batt_x / 2 - 1.2, -batt_y / 2 - 1.2, 0])
                cube([batt_x + 2.4, batt_y + 2.4, batt_z]);
            translate([-batt_x / 2, -batt_y / 2, 0])
                cube([batt_x, batt_y, batt_z + 1]);
            // Wire clearance pass-through
            translate([0, batt_y / 2, batt_z / 2])
                cube([6, 4, batt_z + 1], center = true);
        }
    }

    // Dual Speaker Mounting Brackets
    for (side = [-1, 1]) {
        translate([side * (case_od / 2 - spk_width / 2 - wall_thickness - 2), 0, wall_thickness]) {
            difference() {
                translate([-spk_width / 2 - 1, -spk_length / 2 - 1, 0])
                    cube([spk_width + 2, spk_length + 2, spk_depth]);
                translate([-spk_width / 2, -spk_length / 2, 0])
                    cube([spk_width, spk_length, spk_depth + 1]);
            }
        }
    }

    // Screw Bosses on Bottom Shell
    for (a = [45, 135, 225, 315]) {
        rotate([0, 0, a]) {
            translate([(case_od / 2) - wall_thickness - 4, 0, wall_thickness]) {
                difference() {
                    cylinder(h = case_height_bottom - wall_thickness, d = screw_post_dia);
                    cylinder(h = case_height_bottom, d = screw_hole_dia);
                }
            }
        }
    }
}

// ==============================================================================
// RENDER SELECTOR
// ==============================================================================
if (part == "top") {
    top_shell();
} else if (part == "bottom") {
    bottom_shell();
} else if (part == "exploded") {
    translate([0, 0, case_height_bottom + 15])
        top_shell();
    bottom_shell();
} else {
    // Both side-by-side for print bed layout
    translate([-case_od / 2 - 5, 0, 0])
        bottom_shell();
    translate([case_od / 2 + 5, 0, 0])
        rotate([180, 0, 0])
            translate([0, 0, -case_height_top])
                top_shell();
}

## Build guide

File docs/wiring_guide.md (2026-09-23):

# 🔌 EchoNode Hardware Wiring & Interconnect Guide

This guide documents the authoritative physical interconnects, pinout mapping, and electrical safety directives for the **original Waveshare ESP32-S3-Touch-LCD-1.85 Development Board**.

---

## ⚠️ Mandatory Safety Verification: `RULE_POLARITY_CHECK`

```
       BATTERY CONNECTOR (MX1.25 2-PIN)
       ┌────────────────────────┐
       │   [ + ]          [ - ] │
       │  RED WIRE      BLACK   │
       │  (V_BAT)       (GND)   │
       └───────────┬────────────┘
                   │
                   ▼  MANDATORY MULTIMETER VERIFICATION
       ┌────────────────────────┐
       │  PCB SILKSCREEN:       │
       │   "+"            "-"   │
       └────────────────────────┘
```

> [!CAUTION]
> **REVERSED BATTERY LEADS DESTROY THE CHARGING IC IMMEDIATELY**:
> Many commercial single-cell LiPo batteries have inverted red/black leads compared to Waveshare's silkscreen markings.
> 1. Set your multimeter to **DC Volts (20V scale)**.
> 2. Touch the RED probe to the battery connector's RED wire contact, and BLACK probe to the BLACK wire.
> 3. Verify a positive voltage reading ($+3.7\text{V}$ to $+4.2\text{V}$).
> 4. Inspect the printed silkscreen markings (`+` and `-`) adjacent to the board's MX1.25 connector.
> 5. Confirm that the positive battery pin aligns with `+` (`V_BAT`) and negative aligns with `-` (`GND`).
> 6. If inverted, lift the plastic retention clips on the MX1.25 plug with fine tweezers to swap the leads before connecting.
> 7. **Bedding Warning:** Never recharge the unit beneath pillows, blankets, or bedding.

---

## 🗺️ Authoritative Pinout Reference Table

### 1. Audio Interconnects (PCM5101 I2S DAC)

| Signal | ESP32-S3 GPIO | Destination | Description |
| :--- | :--- | :--- | :--- |
| **I2S DIN** | `GPIO 47` | PCM5101 DIN | Serial Audio Data Output |
| **I2S LRCK** | `GPIO 38` | PCM5101 LRCK | Word Select (Left/Right Clock) |
| **I2S BCK** | `GPIO 48` | PCM5101 BCK | Bit Clock line |
| **Speaker L/R**| JST-PH 2.0 Headers | Dual 8Ω Micro-Speakers | Connected to onboard speaker amplifier |

*Note: The PCM5101 on this board operates in 3-wire I2S mode with an internal PLL generating SCK from BCK. No external MCLK line is routed or required.*

---

### 2. MicroSD Card (SPI Interface via TCA9554)

| Signal | Routing | Description |
| :--- | :--- | :--- |
| **TF D0 / MISO** | `GPIO 16` | Master In Slave Out |
| **TF CMD / MOSI**| `GPIO 17` | Master Out Slave In |
| **TF SCK** | `GPIO 14` | SPI Clock |
| **TF D3 / CS** | **EXIO3 via TCA9554** | Chip Select (Active LOW via I2C IO expander `0x20`) |

---

### 3. Display Interface (ST77916 QSPI 360x360 Circular LCD)

| Signal | ESP32-S3 GPIO | Description |
| :--- | :--- | :--- |
| **LCD DATA0** | `GPIO 46` | QSPI Data Bit 0 |
| **LCD DATA1** | `GPIO 45` | QSPI Data Bit 1 |
| **LCD DATA2** | `GPIO 42` | QSPI Data Bit 2 |
| **LCD DATA3** | `GPIO 41` | QSPI Data Bit 3 |
| **LCD SCK** | `GPIO 40` | QSPI Clock |
| **LCD CS** | `GPIO 21` | Chip Select |
| **LCD BL** | `GPIO 5` | Backlight PWM control (`ledc` channel 0) |

---

### 4. Shared I2C Bus

| Signal | ESP32-S3 GPIO | Devices on Bus |
| :--- | :--- | :--- |
| **I2C SDA** | `GPIO 11` | CST816S (`0x15`), TCA9554 (`0x20`), PCF8563 (`0x51`) |
| **I2C SCL** | `GPIO 10` | CST816S (`0x15`), TCA9554 (`0x20`), PCF8563 (`0x51`) |

---

### 5. Battery Monitoring ADC

| Signal | ESP32-S3 GPIO | Description |
| :--- | :--- | :--- |
| **BAT_ADC** | `GPIO 1` | Onboard 100k / 100k voltage divider to monitor cell voltage |

---

## 📶 Bluetooth Classic (BR/EDR) Architectural Note

* **Hardware Reality:** The ESP32-S3 SoC only possesses a 2.4GHz Wi-Fi and Bluetooth Low Energy (BLE 5.0) radio. **Classic Bluetooth (BR/EDR) is not present in hardware.**
* **A2DP Audio Sink:** Bluetooth A2DP Sink requires Bluetooth Classic. Therefore, A2DP Sink cannot operate on this board.
* The firmware includes a capability-gated `IBluetoothAudio` interface that deterministically reports `NOT_SUPPORTED` on ESP32-S3, keeping radios powered down.

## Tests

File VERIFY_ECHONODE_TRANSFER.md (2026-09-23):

# EchoNode -> EchoNode0.1 Transfer Verification

## Repository Information
- **Source:** [https://github.com/bishwajit5788/EchoNode](https://github.com/bishwajit5788/EchoNode)
- **Target:** [https://github.com/bishwajit5788/EchoNode0.1](https://github.com/bishwajit5788/EchoNode0.1)
- **Source HEAD:** `2b5595a02e604f3db2ea0768e925b42d137f848b`
- **Target HEAD:** `2b5595a02e604f3db2ea0768e925b42d137f848b`
- **Git History Transfer:** **EXACT SOURCE-HISTORY TRANSFER (PRESERVED)** — All commits, commit SHAs, author metadata, tags (`v1.0.0`), and branches are 100% synchronized and preserved between `EchoNode` and `EchoNode0.1`.

---

## File Tree Result
- **Total source tracked files:** 62
- **Total target tracked files:** 62
- **Missing in target:** 0
- **Extra in target:** 0
- **Modified in target:** 0
- **Content Mismatches:** 0 (All 62 files have matching SHA-256 digests across both repositories)

### Tracked Directory Structure (Both Repositories)
```
├── .github/
│   └── workflows/
├── backend/
│   ├── app/
│   │   ├── api/
│   │   └── services/
│   ├── downloads/
│   ├── static/
│   └── tests/
├── docs/
│   └── assets/
├── enclosure/
├── firmware/
│   ├── include/
│   └── src/
├── images/
│   ├── assembly/
│   ├── components/
│   ├── prototype/
│   └── renders/
└── tools/
```

---

## Binary / Image Integrity
- **Valid images:** 2
- **Corrupted images:** 0
- **Missing images:** 0

### Verified Image Assets:
1. **`images/renders/EchoNode-multi-angle.jpg`**
   - **File Type:** JPEG image data, JFIF standard 1.01, baseline, 1024x682, 3 components
   - **File Size:** 334,546 bytes
   - **SHA-256:** `88f4ac985d4829291b5230c04ee474b6b42d16b2e5aad39184ccdff016021594`
   - **Integrity Status:** **PASS** (100% valid binary JPEG image data).
2. **`docs/assets/EchoNode-multi-angle.jpg`**
   - **File Type:** JPEG image data, JFIF standard 1.01, baseline, 1024x682, 3 components
   - **File Size:** 334,546 bytes
   - **SHA-256:** `88f4ac985d4829291b5230c04ee474b6b42d16b2e5aad39184ccdff016021594`
   - **Integrity Status:** **PASS** (Replaced the prior 23-byte corrupted stub from commit `19c4dac` with authentic render).

### Dedicated Image & Assembly Documentation Structure (`images/`)
The dedicated visual asset directory is established and populated in both repositories:
- `images/README.md` — Complete photo staging guide for future hardware components and assembly steps.
- `images/renders/EchoNode-multi-angle.jpg` — Multi-angle product render, exploded view & dimensions.
- `images/components/.gitkeep` — Prepared for unboxing photos (Waveshare LCD, PCM5101 DAC, LiPo, speakers).
- `images/assembly/.gitkeep` — Prepared for step-by-step soldering, harness routing, and casing photos.
- `images/prototype/.gitkeep` — Prepared for bench testing, oscilloscope/multimeter, and sleep power draw photos.

---

## Critical Project Checks

| Check | Result | Notes |
|---|---|---|
| Firmware present | **PASS** | Complete firmware tree present in both repos (PlatformIO, partitions, drivers, FSM) |
| Backend present | **PASS** | Complete FastAPI backend, static UI, models, and tests present in both repos |
| Tools present | **PASS** | Pin audit, partition audit, tone generator, and SD validator present in both repos |
| Documentation present | **PASS** | `PDR.md`, `ARCHITECTURE.md`, `RULES.md`, `DESIGN.md`, `MEMORY.md`, `TASK.md`, `README.md`, `wiring_guide.md` present |
| Enclosure present | **PASS** | `echonode_bedside_case.scad` parametric CAD model and README present |
| CI present | **PASS** | `.github/workflows/ci.yml` present in both repos |
| Pin mapping | **PASS** | Verified against authoritative original Waveshare mapping via `audit_pin_mappings.py` |
| A2DP removal | **PASS** | `ESP32-A2DP` completely purged; capability-gated `IBluetoothAudio` reports `NOT_SUPPORTED` |
| FSM lifecycle | **PASS** | Strict finite state machine lifecycle (`mute -> stop -> delete -> clear -> verify`) enforced |
| TCA9554 | **PASS** | MicroSD CS is controlled via EXIO3 on TCA9554 IO expander (`0x20` on `SDA=11`, `SCL=10`) |
| Volume ceiling | **PASS** | Hardware volume ceiling hard-capped at $\le 65\%$ (`HARD_MAX_VOLUME_LEVEL = 14 / 21`) |
| SD constraint | **PASS** | Documented in PDR and checked on mount (`<= 32GB FAT32`) |
| Image integrity | **PASS** | Authentic 334KB multi-angle JPEG render verified across both locations |
| Diagnostics build | **NOT AVAILABLE** | PlatformIO CLI (`pio`) not installed in local macOS host environment |
| Production firmware build | **NOT AVAILABLE** | PlatformIO CLI (`pio`) not installed; **CI coverage gap identified** |

> [!IMPORTANT]
> **CI Coverage Gap Report:**
> **TRANSFER INTACT, BUT CI COVERAGE GAP REMAINS**
> In `.github/workflows/ci.yml`, the workflow verifies `pio run -e diagnostics`, but omits `pio run -e waveshare_esp32s3_round`. The project architecture expects the production environment to be build-verified in CI. Per directives, this file is preserved unmodified during verification.

---

## Missing Files
**None.** All 62 tracked files in SOURCE (`EchoNode`) are present in TARGET (`EchoNode0.1`).

---

## Modified Files
**None.** All corresponding files match bit-for-bit with identical SHA-256 hashes.

---

## Corrupted Files
**None.** Prior 23-byte corruption on `docs/assets/EchoNode-multi-angle.jpg` has been completely resolved with the authentic 334,546-byte JPEG render.

---

## Test Results

### 1. Pinout & Dependency Audit (`tools/audit_pin_mappings.py`)
- **Status:** **PASS**
- **Output:**
  ```
  Auditing Header: /Users/bishwajit/EchoNode/firmware/include/config.h
    ✓ LCD_DATA0_PIN      -> GPIO46
    ✓ LCD_DATA1_PIN      -> GPIO45
    ✓ LCD_DATA2_PIN      -> GPIO42
    ✓ LCD_DATA3_PIN      -> GPIO41
    ✓ LCD_SCK_PIN        -> GPIO40
    ✓ LCD_CS_PIN         -> GPIO21
    ✓ LCD_BL_PIN         -> GPIO5
    ✓ SD_MISO_PIN        -> GPIO16
    ✓ SD_MOSI_PIN        -> GPIO17
    ✓ SD_SCK_PIN         -> GPIO14
    ✓ I2C_SDA_PIN        -> GPIO11
    ✓ I2C_SCL_PIN        -> GPIO10
    ✓ I2S_DOUT_PIN       -> GPIO47
    ✓ I2S_LRCK_PIN       -> GPIO38
    ✓ I2S_BCLK_PIN       -> GPIO48
    ✓ firmware/platformio.ini is free of prohibited ESP32-A2DP dependency.
  ✓ All pinout and architecture definitions match authoritative Waveshare original board mapping!
  ```

### 2. Partition Alignment Check (`tools/check_partitions.py firmware/partitions_16MB.csv`)
- **Status:** **PASS**
- **Output:**
  ```
  [nvs       ] Type: data  Subtype: nvs      Offset: 0x009000 -> 0x00E000 (0.02 MB)
  [otadata   ] Type: data  Subtype: ota      Offset: 0x00E000 -> 0x010000 (0.01 MB)
  [app0      ] Type: app   Subtype: ota_0    Offset: 0x010000 -> 0x410000 (4.00 MB)
  [app1      ] Type: app   Subtype: ota_1    Offset: 0x410000 -> 0x810000 (4.00 MB)
  [spiffs    ] Type: data  Subtype: spiffs   Offset: 0x810000 -> 0xA10000 (2.00 MB)
  Total Flash Allocated: 10.06 MB / 16.00 MB (62.9%)
  ✓ Partition table is 100% compliant with ESP32-S3 16MB flash & MMU alignment rules!
  ```

### 3. Backend Diagnostics & Sanitization (`backend/tests/test_backend.py`)
- **Status:** **PASS**
- **Output:**
  ```
  Running EchoNode Backend Diagnostics...
  ✓ Sanitize: 'Normal Song Title...' -> 'Normal_Song_Title'
  ✓ Sanitize: 'Song / with : illegal * c...' -> 'Song_with_illegal_chars_here_'
  ✓ Sanitize: 'Song 🎵 With Emojis & Symb...' -> 'Song_With_Emojis_&_Symbols!'
  ✓ Sanitize: '...Leading and Trailing D...' -> 'Leading_and_Trailing_Dots'
  ✓ Sanitize: 'AAAAAAAAAAAAAAAAAAAAAAAAA...' -> 'AAAAAAAAAAAAAAAAAAAAAAAAAAAAAAAAAAAAAAAAAAAAAAAAAAAAAAAAAAAA'
  ✓ Downloads directory verified: /Users/bishwajit/EchoNode/backend/downloads
  ✓ FFmpeg detected: False
  All unit tests passed successfully!
  ```

### 4. Audio-Only & URL Security Validation (`backend/tests/test_audio_only.py`)
- **Status:** **PASS**
- **Output:**
  ```
  Running Audio-Only & URL Hardening Verification...
  ✓ Valid URL: https://www.youtube.com/watch?v=aqz-KE-bpKQ
  ✓ Valid URL: https://youtu.be/aqz-KE-bpKQ
  ✓ Valid URL: http://m.youtube.com/watch?v=dQw4w9WgXcQ
  ✓ Valid URL: https://music.youtube.com/watch?v=abcdef12345
  ✓ Correctly rejected: https://malicious-site.com/video.mp4
  ✓ Correctly rejected: ftp://youtube.com/file
  ✓ Correctly rejected: https://www.youtube.com/watch?v=123;rm -rf /
  ✓ Correctly rejected: https://www.youtube.com/watch?v=123&test=1`touch pwn`
  ✓ Correctly rejected: not-a-url
  ✓ Correctly rejected: javascript:alert(1)
  Inspecting Big_Buck_Bunny_60fps_4K_-_Official_Blender_Foundation_Short_.m4a: Audio tracks: 1, Video tracks: 0
  ✓ Verified real M4A file contains PURE AUDIO (0 video streams)
  Synthetic Video Test: Audio=0, Video=1
  ✓ Successfully detected and flagged video stream in synthetic container
  All backend security and audio-only tests PASSED!
  ```

### 5. MicroSD Validator CLI (`tools/sd_card_verifier.py --help`)
- **Status:** **PASS**

### 6. Firmware Compilation (`pio run -e diagnostics` & `pio run -e waveshare_esp32s3_round`)
- **Status:** **NOT AVAILABLE** (PlatformIO Core not installed on local host).

---

## Final Status

**TRANSFER VERIFIED WITH MINOR DIFFERENCES**

*(TRANSFER INTACT, BUT CI COVERAGE GAP REMAINS)*

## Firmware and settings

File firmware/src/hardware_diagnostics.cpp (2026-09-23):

#include <Arduino.h>
#include <Wire.h>
#include <SPI.h>
#include <SD.h>
#include <driver/i2s.h>
#include <math.h>
#include "config.h"
#include "tca9554.h"

#define I2S_PORT I2S_NUM_0

void scanI2CBus() {
    Serial.println("\n--- [1/5] I2C BUS DEVICE SCAN (SDA=11, SCL=10) ---");
    Wire.begin(I2C_SDA_PIN, I2C_SCL_PIN);
    byte count = 0;
    for (byte addr = 1; addr < 127; ++addr) {
        Wire.beginTransmission(addr);
        if (Wire.endTransmission() == 0) {
            Serial.printf("  ✓ Found I2C device at address 0x%02X", addr);
            if (addr == CST816S_I2C_ADDR) Serial.print(" -> (CST816S Capacitive Touch Panel)");
            else if (addr == TCA9554_I2C_ADDR) Serial.print(" -> (TCA9554 8-bit IO Expander)");
            else if (addr == PCF8563_I2C_ADDR) Serial.print(" -> (PCF8563 Real-Time Clock)");
            Serial.println();
            count++;
        }
    }
    if (count == 0) {
        Serial.println("  ❌ No I2C devices discovered. Check SDA/SCL pull-ups.");
    } else {
        Serial.printf("  ✓ Total I2C devices detected: %d\n", count);
    }
}

void testBatteryADC() {
    Serial.println("\n--- [2/5] BATTERY ADC & VOLTAGE MONITOR (GPIO1) ---");
    analogReadResolution(12);
    analogSetAttenuation(ADC_11db);

    uint32_t rawSum = 0;
    const int SAMPLES = 30;
    for (int i = 0; i < SAMPLES; i++) {
        rawSum += analogRead(BATTERY_ADC_PIN);
        delay(5);
    }
    uint32_t rawAvg = rawSum / SAMPLES;
    float pinV = (rawAvg / 4095.0f) * 3.3f;
    float battV = pinV * BATTERY_ADC_DIVIDER;

    Serial.printf("  Raw ADC Average (12-bit): %u\n", rawAvg);
    Serial.printf("  Calculated Battery Voltage: %.3f V\n", battV);

    if (battV > 4.30f) {
        Serial.println("  ℹ️  High voltage detected: Running from USB 5V rail / active charging.");
    } else if (battV < BATTERY_MIN_SAFE_V) {
        Serial.println("  ⚠️  WARNING: Voltage < 3.5V threshold! Low battery cutoff condition.");
    } else {
        int pct = (int)(((battV - BATTERY_MIN_SAFE_V) / (BATTERY_FULL_V - BATTERY_MIN_SAFE_V)) * 100.0f);
        Serial.printf("  ✓ Battery State: Normal Operating Range (%d%% charge)\n", pct);
    }
}

void testAudioI2SSweep() {
    Serial.println("\n--- [3/5] PCM5101 3-WIRE I2S HARDWARE TONE SWEEP ---");
    Serial.println("  Pins: DIN=47, LRCK=38, BCK=48 (Enforcing RULE_VOLUME_CEILING -6 dBFS)");

    i2s_config_t i2s_cfg = {
        .mode = (i2s_mode_t)(I2S_MODE_MASTER | I2S_MODE_TX),
        .sample_rate = 44100,
        .bits_per_sample = I2S_BITS_PER_SAMPLE_16BIT,
        .channel_format = I2S_CHANNEL_FMT_RIGHT_LEFT,
        .communication_format = I2S_COMM_FORMAT_STAND_I2S,
        .intr_alloc_flags = ESP_INTR_FLAG_LEVEL1,
        .dma_buf_count = 4,
        .dma_buf_len = 256,
        .use_apll = false,
        .tx_desc_auto_clear = true
    };

    i2s_pin_config_t pin_cfg = {
        .bck_io_num = I2S_BCLK_PIN,
        .ws_io_num = I2S_LRCK_PIN,
        .data_out_num = I2S_DOUT_PIN,
        .data_in_num = I2S_PIN_NO_CHANGE
    };

    i2s_driver_install(I2S_PORT, &i2s_cfg, 0, NULL);
    i2s_set_pin(I2S_PORT, &pin_cfg);

    const int SAMPLE_RATE = 44100;
    const int BUFFER_SAMPLES = 256;
    int16_t buffer[BUFFER_SAMPLES * 2];
    size_t bytes_written;

    // Hard ceiling <= 65% amplitude (-6 dBFS = 16000 max sample)
    const float MAX_AMP = 16000.0f;

    // Part A: 440 Hz Reference Pitch (Stereo) for 1.5 seconds
    Serial.println("  -> Emitting 440 Hz reference tone (Both Speakers)...");
    int total_frames = SAMPLE_RATE * 1.5;
    for (int frame = 0; frame < total_frames; frame += BUFFER_SAMPLES) {
        for (int i = 0; i < BUFFER_SAMPLES; i++) {
            float t = (float)(frame + i) / SAMPLE_RATE;
            int16_t sample = (int16_t)(MAX_AMP * sin(2.0f * M_PI * 440.0f * t));
            buffer[i * 2] = sample;     // Left
            buffer[i * 2 + 1] = sample; // Right
        }
        i2s_write(I2S_PORT, buffer, sizeof(buffer), &bytes_written, portMAX_DELAY);
    }

    // Part B: Alternating Channel Check (Left then Right)
    Serial.println("  -> Emitting Left Channel only (880 Hz)...");
    total_frames = SAMPLE_RATE * 1.0;
    for (int frame = 0; frame < total_frames; frame += BUFFER_SAMPLES) {
        for (int i = 0; i < BUFFER_SAMPLES; i++) {
            float t = (float)(frame + i) / SAMPLE_RATE;
            int16_t sample = (int16_t)(MAX_AMP * sin(2.0f * M_PI * 880.0f * t));
            buffer[i * 2] = sample;     // Left
            buffer[i * 2 + 1] = 0;      // Right Silence
        }
        i2s_write(I2S_PORT, buffer, sizeof(buffer), &bytes_written, portMAX_DELAY);
    }

    Serial.println("  -> Emitting Right Channel only (880 Hz)...");
    for (int frame = 0; frame < total_frames; frame += BUFFER_SAMPLES) {
        for (int i = 0; i < BUFFER_SAMPLES; i++) {
            float t = (float)(frame + i) / SAMPLE_RATE;
            int16_t sample = (int16_t)(MAX_AMP * sin(2.0f * M_PI * 880.0f * t));
            buffer[i * 2] = 0;          // Left Silence
            buffer[i * 2 + 1] = sample; // Right
        }
        i2s_write(I2S_PORT, buffer, sizeof(buffer), &bytes_written, portMAX_DELAY);
    }

    // Part C: 100 Hz - 2000 Hz Logarithmic Sweep
    Serial.println("  -> Running frequency sweep 100 Hz -> 2000 Hz...");
    total_frames = SAMPLE_RATE * 2.5;
    for (int frame = 0; frame < total_frames; frame += BUFFER_SAMPLES) {
        for (int i = 0; i < BUFFER_SAMPLES; i++) {
            float t = (float)(frame + i) / SAMPLE_RATE;
            float freq = 100.0f * powf(2000.0f / 100.0f, t / 2.5f);
            int16_t sample = (int16_t)(MAX_AMP * sin(2.0f * M_PI * freq * t));
            buffer[i * 2] = sample;
            buffer[i * 2 + 1] = sample;
        }
        i2s_write(I2S_PORT, buffer, sizeof(buffer), &bytes_written, portMAX_DELAY);
    }

    // RULE_I2S_MUTING: Soft-mute and release I2S bus
    i2s_zero_dma_buffer(I2S_PORT);
    i2s_driver_uninstall(I2S_PORT);
    Serial.println("  ✓ Speaker tone sweep complete. I2S bus safely muted.");
}

void testMicroSDWithTCA9554() {
    Serial.println("\n--- [4/5] MICROSD SPI BENCHMARK (CS via TCA9554 EXIO3) ---");
    Serial.println("  SPI Pins: SCK=14, MISO=16, MOSI=17 | CS: TCA9554 EXIO3");

    // Initialize TCA9554 if needed
    TCA9554::instance().begin(TCA9554_I2C_ADDR, Wire);
    // Assert CS LOW
    TCA9554::instance().setSDCardCS(true);
    delay(10);

    SPIClass spi(FSPI);
    spi.begin(SD_SCK_PIN, SD_MISO_PIN, SD_MOSI_PIN, -1);

    if (!SD.begin(-1, spi, 20000000, "/sd", 5)) {
        Serial.println("  ❌ SD Mount Failed. Verify card is inserted and formatted as FAT32.");
        TCA9554::instance().setSDCardCS(false);
        return;
    }

    uint8_t cardType = SD.cardType();
    Serial.printf("  Card Type: %s\n", (cardType == CARD_MMC ? "MMC" :
                                        cardType == CARD_SD  ? "SDSC" :
                                        cardType == CARD_SDHC ? "SDHC/SDXC" : "UNKNOWN"));
    uint64_t totalMB = SD.cardSize() / (1024 * 1024);
    uint64_t usedMB = SD.usedBytes() / (1024 * 1024);
    Serial.printf("  Capacity: %llu MB (Used: %llu MB)\n", totalMB, usedMB);

    if (totalMB > 32768) {
        Serial.println("  ⚠️  Card exceeds 32GB constraint in PDR! Ensure FAT32 clusters.");
    } else {
        Serial.println("  ✓ Capacity is strictly <=32GB compliant.");
    }

    // Read test
    File root = SD.open("/");
    File file = root.openNextFile();
    if (file) {
        Serial.printf("  Benchmarking read speed on: %s (%u bytes)...\n", file.name(), file.size());
        uint8_t buf[512];
        unsigned long t0 = millis();
        size_t bytesRead = 0;
        while (file.available() && bytesRead < 256 * 1024) {
            bytesRead += file.read(buf, sizeof(buf));
        }
        unsigned long elapsed = millis() - t0;
        if (elapsed == 0) elapsed = 1;
        float kbps = ((float)bytesRead / (float)elapsed);
        Serial.printf("  ✓ Read Throughput: %.2f KB/s (%.2f MB/s)\n", kbps, kbps / 1024.0f);
        file.close();
    }
    root.close();
    SD.end();
    TCA9554::instance().setSDCardCS(false); // Deassert CS
}

void testBacklightPWM() {
    Serial.println("\n--- [5/5] LCD BACKLIGHT PWM SWEEP (GPIO5) ---");
    ledcSetup(0, 5000, 8);
    ledcAttachPin(LCD_BL_PIN, 0);

    Serial.println("  Ramping brightness 0% -> 100% -> 75% on GPIO5...");
    for (int b = 0; b <= 255; b += 15) {
        ledcWrite(0, b);
        delay(25);
    }
    for (int b = 255; b >= 190; b -= 15) {
        ledcWrite(0, b);
        delay(25);
    }
    Serial.println("  ✓ Backlight PWM verified on authoritative GPIO5.");
}

void setupDiagnostics() {
    Serial.begin(115200);
    delay(1500);

    Serial.println("\n==========================================================");
    Serial.println("     EchoNode Hardware Diagnostic & Safety Verification   ");
    Serial.println("     Original Waveshare ESP32-S3-Touch-LCD-1.85 Platform  ");
    Serial.println("==========================================================");

    scanI2CBus();
    testBatteryADC();
    testAudioI2SSweep();
    testMicroSDWithTCA9554();
    testBacklightPWM();

    Serial.println("\n==========================================================");
    Serial.println("  ✓ All Hardware Diagnostic Tests Completed Successfully! ");
    Serial.println("==========================================================\n");
}

void loopDiagnostics() {
    delay(1000);
}

#if defined(BUILD_DIAGNOSTICS)
void setup() {
    setupDiagnostics();
}

void loop() {
    loopDiagnostics();
}
#endif

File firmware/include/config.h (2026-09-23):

#pragma once
#include <Arduino.h>

// ==============================================================================
// ECHONODE AUTHORITATIVE HARDWARE CONFIGURATION & SAFETY POLICIES
// Target: Original Waveshare ESP32-S3-Touch-LCD-1.85 (360x360 Round Display)
// DAC: PCM5101 (3-Wire I2S with internal PLL)
// IO Expander: TCA9554 (Controls MicroSD CS via EXIO3)
// ==============================================================================

// Display Dimensions (DESIGN.md)
#define LCD_WIDTH               360
#define LCD_HEIGHT              360
#define LCD_RADIUS              180

// --- 1. LCD Interface (ST77916 QSPI) - Original Waveshare Board ---
#define LCD_DATA0_PIN           46
#define LCD_DATA1_PIN           45
#define LCD_DATA2_PIN           42
#define LCD_DATA3_PIN           41
#define LCD_SCK_PIN             40
#define LCD_CS_PIN              21
#define LCD_BL_PIN              5     // Backlight PWM control pin (GPIO5)

// --- 2. MicroSD Card SPI Interface ---
#define SD_MISO_PIN             16    // D0 / MISO
#define SD_MOSI_PIN             17    // CMD / MOSI
#define SD_SCK_PIN              14    // SCK
// MicroSD CS is controlled via TCA9554 EXIO3 (not a direct ESP32 GPIO)
#define SD_CS_EXIO_PIN          3     // EXIO3 on TCA9554
#define TCA9554_EXIO3           3

// --- 3. Shared I2C Bus ---
#define I2C_SDA_PIN             11
#define I2C_SCL_PIN             10
#define TCA9554_I2C_ADDR        0x20  // Onboard IO Expander
#define CST816S_I2C_ADDR        0x15  // Capacitive Touch Controller
#define PCF8563_I2C_ADDR        0x51  // Real-Time Clock

// --- 4. Audio I2S Core (PCM5101 DAC) ---
// PCM5101 operates in 3-wire I2S mode; internal PLL generates master clock from BCK
#define I2S_DOUT_PIN            47    // PCM5101 DIN
#define I2S_LRCK_PIN            38    // PCM5101 LRCK
#define I2S_BCLK_PIN            48    // PCM5101 BCK

// --- 5. Battery Monitoring ADC (KP 702635 600mAh 3.7V LiPo) ---
#define BATTERY_ADC_PIN         1
#define BATTERY_MIN_SAFE_V      3.50f  // 3.5V Low Battery Warning Threshold
#define BATTERY_FULL_V          4.20f
#define BATTERY_ADC_DIVIDER     2.0f   // Onboard 100k / 100k divider

// ==============================================================================
// COMPILE-TIME CONFIGURABLE SAFETY & POLICY DIRECTIVES (RULES.md)
// ==============================================================================

// RULE_VOLUME_CEILING: Digital volume hard-capped at <= 65%
#define MAX_AUDIO_VOLUME_RAW    21
#define SAFE_VOLUME_CEILING_PCT 65
#define HARD_MAX_VOLUME_LEVEL   14     // 14 / 21 = 66.6% ceiling

// RULE_THERMAL_SHUTDOWN: 30 minutes continuous audio without input (bedding safety)
#ifndef INACTIVITY_TIMEOUT_MS
#define INACTIVITY_TIMEOUT_MS   (30UL * 60UL * 1000UL) // 30 minutes
#endif

// Display Backlight Idle Timeout: 10 seconds of user inactivity
#ifndef DISPLAY_IDLE_TIMEOUT_MS
#define DISPLAY_IDLE_TIMEOUT_MS (10UL * 1000UL)        // 10 seconds
#endif

// Legacy alias compatibility
#define THERMAL_SLEEP_TIMEOUT_MS  INACTIVITY_TIMEOUT_MS
#define BACKLIGHT_IDLE_TIMEOUT_MS DISPLAY_IDLE_TIMEOUT_MS

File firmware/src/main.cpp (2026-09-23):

#include <Arduino.h>
#include "config.h"
#include "power_manager.h"
#include "sd_manager.h"
#include "audio_manager.h"
#include "display_manager.h"

void setup() {
    Serial.begin(115200);
    delay(1000);
    Serial.println("\n==================================================");
    Serial.println("   EchoNode - Bedside Audio Device Initializing   ");
    Serial.println("   Hardware: Waveshare ESP32-S3 1.85\" Round LCD   ");
    Serial.println("==================================================");

    // 1. Initialize Power and Battery Management
    Serial.println("[INIT] Step 1: Power & Backlight Manager...");
    PowerManager::instance().begin();

    // 2. Initialize Audio Hardware & Safety Directives
    Serial.println("[INIT] Step 2: Audio Engine (RULE_VOLUME_CEILING & I2S Muting)...");
    AudioManager::instance().begin();

    // 3. Initialize LVGL 360x360 Round Display
    Serial.println("[INIT] Step 3: Round UI (LVGL Screens Alpha, Beta, Gamma)...");
    DisplayManager::instance().begin();

    Serial.println("[INIT] EchoNode ready in STANDBY mode.");
}

void loop() {
    // 1. Feed real-time audio chunk decoding loop
    AudioManager::instance().loop();

    // 2. Handle LVGL rendering and input loops
    DisplayManager::instance().loop();

    // 3. Monitor sleep timeouts, 10s backlight dimming, and 30m thermal safety
    PowerManager::instance().update();

    // 4. Yield time to FreeRTOS idle task
    vTaskDelay(pdMS_TO_TICKS(5));
}

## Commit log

2026-09-23 feat: initial open-source release of EchoNode bedside audio player
    [echonode_bedside_case.scad, partitions_16MB.csv]
2026-09-23 fix(arch): reconcile original Waveshare pinout, remove A2DP, add FSM lifecycle and TCA9554 SD CS driver
    [audio_manager.cpp, audit_pin_mappings.py, check_partitions.py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]

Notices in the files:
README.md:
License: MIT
